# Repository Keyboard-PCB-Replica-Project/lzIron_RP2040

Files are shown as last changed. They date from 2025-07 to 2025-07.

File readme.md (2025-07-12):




LZ Iron 레플리카 PCB입니다. 

RGB LED 외의 LED(인디케이터)는 따로 부착해두지 않았습니다.

KT-0805W LED를 구입해서 LED 자리에 납땜해주시면 됩니다. 타오바오나 알리에서 같이 주문해주시면 되며,

납땜 난이도는 스위치보다도 못한 수준입니다.

물론 돈이 더 들어도 괜찮다면, LED까지 부착이 된 채로 배송 오는 옵션을 구현해두겠습니다.

이 기판은 MX 버전이며, ISO 엔터 및 Alps를 지원하지 않습니다!

추후에 추가될 수도 있습니다.

솔더링 버전이며, 아직 제작 후 제대로된 검증이 이뤄지지 않은 상태입니다!

검수는 꼼꼼이 했습니다.

이 기판은 LED와 USB가 전부 기판 전면부에 있기 때문에, 그 외의 SMD 부품들도 전부 전면메 배치했습니다.

간섭은 획인되지 않으나, 폼을 끼우고 빌드할 시 쇼트가 발생할 수 있습니다. 조심해주세요!

그리고 제가 실물 기판이 없어서, 사진을 보고 따 두었습니다.
스위치나 하우징과의 간섭이 없을지 이미지를 보고 잘 확인해보고 주문해주셨으면 해요.
저도 몇번씩 체크했지만 혹시 모르니까 재차 확인 부탁드려요!!

추가 필요 부품 : KT-0805W LED

작동 확인 여부 : 아직 확인되지 않음

----------------------------------------------------------

This is a replica PCB of the LZ Iron.

Indicator LEDs (other than RGB) are not included.

If you want them, you can buy KT-0805W LEDs and solder them yourself.

They’re easy to find on Taobao or AliExpress, and the soldering is even easier than doing switches.

If you're okay with spending a bit more, I might offer a version with the LEDs pre-installed later on.

This PCB supports MX switches only.

It doesn’t support ISO Enter or Alps switches (at least not yet — maybe in the future).

This is a solder-only version, and it hasn’t been fully tested yet.

But I did check everything carefully.

All components, including the LEDs and USB connector, are placed on the front side of the PCB.

Other SMD parts are also on the front.

There shouldn’t be any interference, but if you use case foam, be careful — there’s a chance of shorting.

Extra parts needed: KT-0805W LEDs

Tested and working: Not verified yet

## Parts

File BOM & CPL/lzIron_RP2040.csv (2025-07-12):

Reference | Value | Footprint | LCSC Part Number
C1,C2,C3,C4,C5,C6,C7,C8,C10,C11,C17,LC1,LC2,LC3,LC4,LC5,LC6,LC7,LC8 | 100n | C_0402 | C1525
C9,C12,C13,C14 | 1u | C_0402 | C52923
C15,C16 | 15p | C_0402 | C1548
D1,D2,D3,D4,D5,D6,D7,D8,D9,D10,D11,D12,D13,D14,D15,D16,D17,D18,D19,D20,D21,D22,D23,D24,D25,D26,D27,D28,D29,D30,D31,D32,D33,D34,D35,D36,D37,D38,D39,D40,D41,D42,D43,D44,D45,D46,D47,D48,D49,D50,D51,D52,D53,D54,D55,D56,D57,D58,D59,D60,D61,D62,D63,D64,D65,D66,D67,D68,D69,D70,D71,D72,D73,D74,D75,D76,D77,D78,D79,D80,D81,D82,D83,D84,D85,D86,D87,D88,D89 | D_Small | SOD-123 | C81598
F1 | Fuse_Small | F_0805 | C20978
J1 | USB_C_Receptacle_USB2.0_16P | USB_C_Receptacle_16P | C165948
R1,R2 | 27.4R | C_0603 | C25190
R3 | 10k | C_0402 | C25744
R4,R6 | 1k | C_0402 | C11702
R5,R8,R11 | 300R | C_0402 | C25102
R9,R10 | 5.1k | C_0402 | C25905
U1 | XC6206P332MR | SOT-23 | C5446
U2 | W25Q128JVS | SOIC-8_5.23x5.23mm | C97521
U3 | RP2040 | RP2040-QFN-56 | C2040
U4 | SRV05-4 | SOT-23-6 | C7420376
ULED1,ULED2,ULED3,ULED4,ULED5,ULED6,ULED7,ULED8 | SK6812MINI-HS | LED_SK6812MINI-HS | C2922787
Y1 | ABM8-272-T3 | XO32-4Pin_3.2x2.5 | C20625731

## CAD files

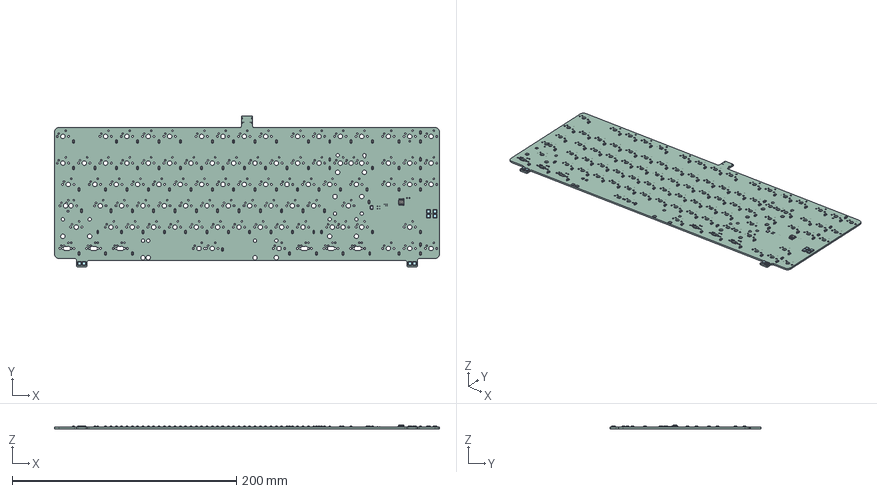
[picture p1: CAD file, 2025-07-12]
lzIron.step
343.7 x 135.1 x 3.50 mm
root x 89
SOIC8_P1-27_L5-0_W4-0
Product x 8
lzIron 1.67.1
lzIron 1.67.2
_autosave-lzIron_RP2040_PCB

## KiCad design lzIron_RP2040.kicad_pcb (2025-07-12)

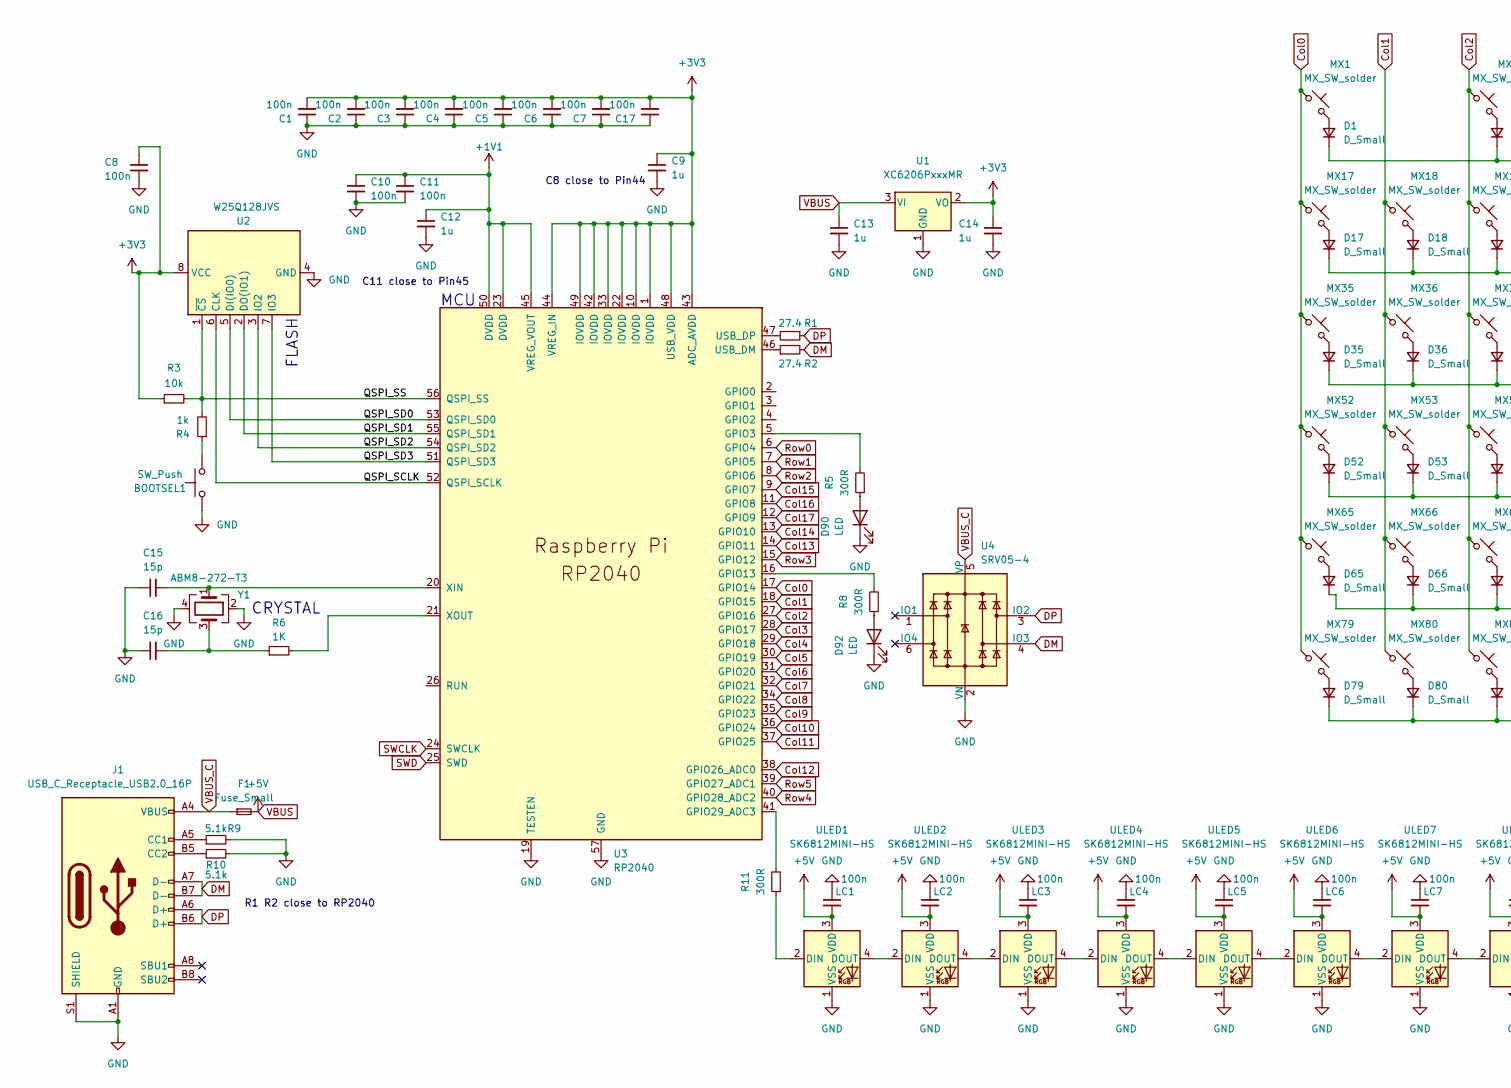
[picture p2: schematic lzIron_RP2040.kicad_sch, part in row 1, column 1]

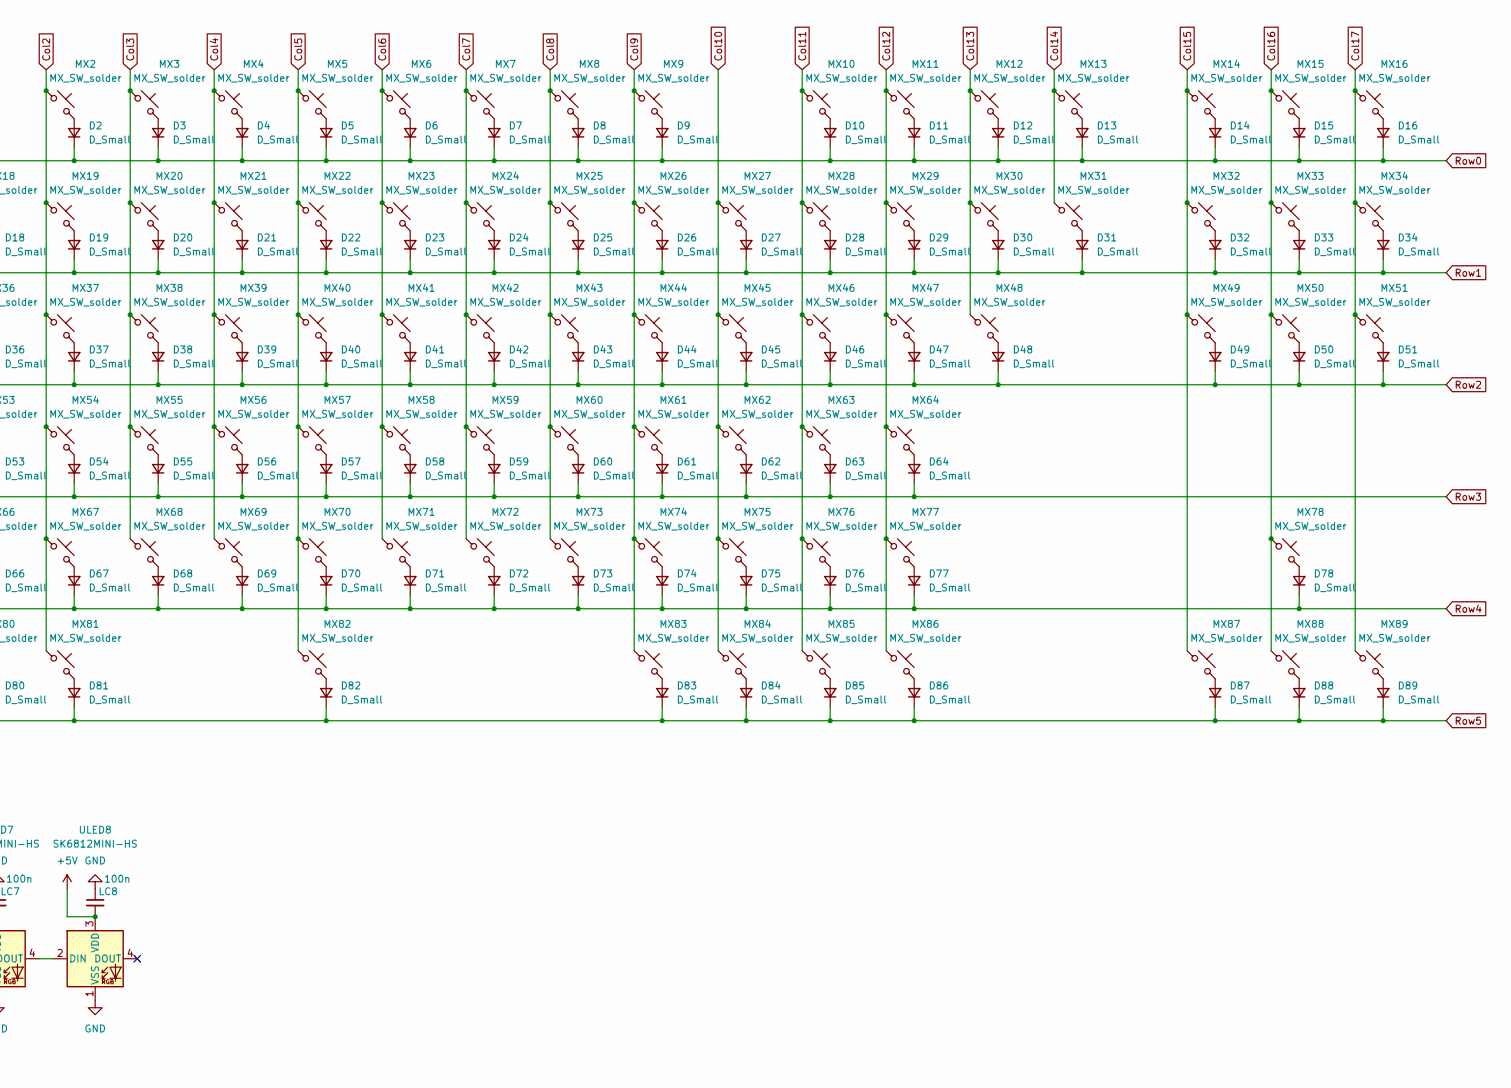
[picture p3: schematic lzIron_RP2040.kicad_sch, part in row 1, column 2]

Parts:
BOOTSEL1: SW_Push; two hole
C1, C2, C3, C4, C5, C6, C7, C8, C10, C11, C17: 100n; C_0402_1005Metric
C9, C12, C13, C14: 1u; C_0402_1005Metric
C15, C16: 15p; C_0402_1005Metric
D1, D2, D3, D4, D5, D6, D7, D8, D9, D10, D11, D12, D13, D14, D15, D16, D17, D18, D19, D20, D21, D22, D23, D24, D25, D26, D27, D28, D29, D30, D31, D32, D33, D34, D35, D36, D37, D38, D39, D40, D41, D42, D43, D44, D45, D46, D47, D48, D49, D50, D51, D52, D53, D54, D55, D56, D57, D58, D59, D60, D61, D62, D63, D64, D65, D66, D67, D68, D69, D70, D71, D72, D73, D74, D75, D76, D77, D78, D79, D80, D81, D82, D83, D84, D85, D86, D87, D88, D89: D_Small; Diode_SOD-123_noref2
D90, D92: LED; KT-0805W
F1: Fuse_Small; Fuse_0805_2012Metric_Pad1.15x1.40mm_HandSolder
J1: USB_C_Receptacle_USB2.0_16P; USB_C_Receptacle_GCT_USB4105-xx-A_16P_TopMnt_Horizontal
LC1, LC2, LC3, LC4, LC5, LC6, LC7, LC8: 100n; C_0402_1005Metric_noref
MX1, MX2, MX3, MX4, MX5, MX6, MX7, MX8, MX9, MX10, MX11, MX12, MX13, MX14, MX15, MX16, MX17, MX18, MX19, MX20, MX21, MX22, MX23, MX24, MX25, MX26, MX27, MX28, MX29, MX30, MX31, MX32, MX33, MX34, MX35, MX36, MX37, MX38, MX39, MX40, MX41, MX42, MX43, MX44, MX45, MX46, MX47, MX48, MX49, MX50, MX51, MX52, MX53, MX54, MX55, MX56, MX57, MX58, MX59, MX60, MX61, MX62, MX63, MX64, MX65, MX66, MX67, MX68, MX69, MX70, MX71, MX72, MX73, MX74, MX75, MX76, MX77, MX78, MX79, MX80, MX81, MX82, MX83, MX84, MX85, MX86, MX87, MX88, MX89: MX_SW_solder; MX_PCB_1.00u_NoSilkscreen3
R1, R2: 27.4; C_0603_1608Metric
R3: 10k; C_0402_1005Metric
R4: 1k; C_0402_1005Metric
R5, R8, R11: 300R; C_0402_1005Metric
R6: 1K; C_0402_1005Metric
R9, R10: 5.1k; C_0402_1005Metric
U1: XC6206PxxxMR; SOT-23
U2: W25Q128JVS; SOIC-8_5.23x5.23mm_P1.27mm
U3: RP2040; RP2040-QFN-56
U4: SRV05-4; SOT-23-6
ULED1, ULED2, ULED3, ULED4, ULED5, ULED6, ULED7, ULED8: SK6812MINI-HS; LED_SK6812MINI_PLCC4_3.5x3.5mm_P1.75mm_2
Y1: ABM8-272-T3; Oscillator_SMD_EuroQuartz_XO32-4Pin_3.2x2.5mm

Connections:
+1V1: C10.1, C11.1, C12.1, U3.23 (DVDD), U3.45 (VREG_VOUT), U3.50 (DVDD)
+3V3: C1.2, C2.2, C3.2, C4.2, C5.2, C6.2, C7.2, C8.1, C9.1, C14.1, C17.2, R3.1, U1.2 (VO), U2.8 (VCC), U3.1 (IOVDD), U3.10 (IOVDD), U3.22 (IOVDD), U3.33 (IOVDD), U3.42 (IOVDD), U3.43 (ADC_AVDD), U3.44 (VREG_IN), U3.48 (USB_VDD), U3.49 (IOVDD)
/QSPI_SCLK: U2.6 (CLK), U3.52 (QSPI_SCLK)
/QSPI_SD0: U2.5 (DI(IO0)), U3.53 (QSPI_SD0)
/QSPI_SD1: U2.2 (DO(IO1)), U3.55 (QSPI_SD1)
/QSPI_SD2: U2.3 (IO2), U3.54 (QSPI_SD2)
/QSPI_SD3: U2.7 (IO3), U3.51 (QSPI_SD3)
/QSPI_SS: R3.2, R4.2, U2.1 (~CS), U3.56 (QSPI_SS)
Col0: MX1.1, MX17.1, MX35.1, MX52.1, MX65.1, MX79.1, U3.17 (GPIO14)
Col1: MX18.1, MX36.1, MX53.1, MX66.1, MX80.1, U3.18 (GPIO15)
Col2: MX2.1, MX19.1, MX37.1, MX54.1, MX67.1, MX81.1, U3.27 (GPIO16)
Col3: MX3.1, MX20.1, MX38.1, MX55.1, MX68.1, U3.28 (GPIO17)
Col4: MX4.1, MX21.1, MX39.1, MX56.1, MX69.1, U3.29 (GPIO18)
Col5: MX5.1, MX22.1, MX40.1, MX57.1, MX70.1, MX82.1, U3.30 (GPIO19)
Col6: MX6.1, MX23.1, MX41.1, MX58.1, MX71.1, U3.31 (GPIO20)
Col7: MX7.1, MX24.1, MX42.1, MX59.1, MX72.1, U3.32 (GPIO21)
Col8: MX8.1, MX25.1, MX43.1, MX60.1, MX73.1, U3.34 (GPIO22)
Col9: MX9.1, MX26.1, MX44.1, MX61.1, MX74.1, MX83.1, U3.35 (GPIO23)
Col10: MX27.1, MX45.1, MX62.1, MX75.1, MX84.1, U3.36 (GPIO24)
Col11: MX10.1, MX28.1, MX46.1, MX63.1, MX76.1, MX85.1, U3.37 (GPIO25)
Col12: MX11.1, MX29.1, MX47.1, MX64.1, MX77.1, MX86.1, U3.38 (GPIO26_ADC0)
Col13: MX12.1, MX30.1, MX48.1, U3.14 (GPIO11)
Col14: MX13.1, MX31.1, U3.13 (GPIO10)
Col15: MX14.1, MX32.1, MX49.1, MX87.1, U3.9 (GPIO7)
Col16: MX15.1, MX33.1, MX50.1, MX78.1, MX88.1, U3.11 (GPIO8)
Col17: MX16.1, MX34.1, MX51.1, MX89.1, U3.12 (GPIO9)
DM: J1.A7 (D-), J1.B7 (D-), R2.2, U4.4 (IO3)
DP: J1.A6 (D+), J1.B6 (D+), R1.1, U4.3 (IO2)
GND: BOOTSEL1.1, C1.1, C2.1, C3.1, C4.1, C5.1, C6.1, C7.1, C8.2, C9.2, C10.2, C11.2, C12.2, C13.2, C14.2, C15.1, C16.1, C17.1, D90.1 (K), D92.1 (K), J1.A1 (GND), J1.A12 (GND), J1.B1 (GND), J1.B12 (GND), J1.S1 (SHIELD), LC1.1, LC2.1, LC3.1, LC4.1, LC5.1, LC6.1, LC7.1, LC8.1, R9.2, R10.2, U1.1 (GND), U2.4 (GND), U3.19 (TESTEN), U3.57 (GND), U4.2 (VN), ULED1.1 (VSS), ULED2.1 (VSS), ULED3.1 (VSS), ULED4.1 (VSS), ULED5.1 (VSS), ULED6.1 (VSS), ULED7.1 (VSS), ULED8.1 (VSS), Y1.2, Y1.4
unnamed: BOOTSEL1.2, R4.1
unnamed: C16.2, R6.1, Y1.3
unnamed: D1.2 (A), MX1.2
unnamed: D2.2 (A), MX2.2
unnamed: D3.2 (A), MX3.2
unnamed: D4.2 (A), MX4.2
unnamed: D5.2 (A), MX5.2
unnamed: D6.2 (A), MX6.2
unnamed: D7.2 (A), MX7.2
unnamed: D8.2 (A), MX8.2
unnamed: D9.2 (A), MX9.2
unnamed: D10.2 (A), MX10.2
unnamed: D11.2 (A), MX11.2
unnamed: D12.2 (A), MX12.2
unnamed: D13.2 (A), MX13.2
unnamed: D14.2 (A), MX14.2
unnamed: D15.2 (A), MX15.2
unnamed: D16.2 (A), MX16.2
unnamed: D17.2 (A), MX17.2
unnamed: D18.2 (A), MX18.2
unnamed: D19.2 (A), MX19.2
unnamed: D20.2 (A), MX20.2
unnamed: D21.2 (A), MX21.2
unnamed: D22.2 (A), MX22.2
unnamed: D23.2 (A), MX23.2
unnamed: D24.2 (A), MX24.2
unnamed: D25.2 (A), MX25.2
unnamed: D26.2 (A), MX26.2
unnamed: D27.2 (A), MX27.2
unnamed: D28.2 (A), MX28.2
unnamed: D29.2 (A), MX29.2
unnamed: D30.2 (A), MX30.2
unnamed: D31.2 (A), MX31.2
unnamed: D32.2 (A), MX32.2
unnamed: D33.2 (A), MX33.2
unnamed: D34.2 (A), MX34.2
unnamed: D35.2 (A), MX35.2
unnamed: D36.2 (A), MX36.2
unnamed: D37.2 (A), MX37.2
unnamed: D38.2 (A), MX38.2
unnamed: D39.2 (A), MX39.2
unnamed: D40.2 (A), MX40.2
unnamed: D41.2 (A), MX41.2
unnamed: D42.2 (A), MX42.2
unnamed: D43.2 (A), MX43.2
unnamed: D44.2 (A), MX44.2
unnamed: D45.2 (A), MX45.2
unnamed: D46.2 (A), MX46.2
unnamed: D47.2 (A), MX47.2
unnamed: D48.2 (A), MX48.2
unnamed: D49.2 (A), MX49.2
unnamed: D50.2 (A), MX50.2
unnamed: D51.2 (A), MX51.2
unnamed: D52.2 (A), MX52.2
unnamed: D53.2 (A), MX53.2
unnamed: D54.2 (A), MX54.2
unnamed: D55.2 (A), MX55.2
unnamed: D56.2 (A), MX56.2
unnamed: D57.2 (A), MX57.2
unnamed: D58.2 (A), MX58.2
unnamed: D59.2 (A), MX59.2
unnamed: D60.2 (A), MX60.2
unnamed: D61.2 (A), MX61.2
unnamed: D62.2 (A), MX62.2
unnamed: D63.2 (A), MX63.2
unnamed: D64.2 (A), MX64.2
unnamed: D65.2 (A), MX65.2
unnamed: D66.2 (A), MX66.2
unnamed: D67.2 (A), MX67.2
unnamed: D68.2 (A), MX68.2
unnamed: D69.2 (A), MX69.2
unnamed: D70.2 (A), MX70.2
unnamed: D71.2 (A), MX71.2
unnamed: D72.2 (A), MX72.2
unnamed: D73.2 (A), MX73.2
unnamed: D74.2 (A), MX74.2
unnamed: D75.2 (A), MX75.2
unnamed: D76.2 (A), MX76.2
unnamed: D77.2 (A), MX77.2
unnamed: D78.2 (A), MX78.2
unnamed: D79.2 (A), MX79.2
unnamed: D80.2 (A), MX80.2
unnamed: D81.2 (A), MX81.2
unnamed: D82.2 (A), MX82.2
unnamed: D83.2 (A), MX83.2
unnamed: D84.2 (A), MX84.2
unnamed: D85.2 (A), MX85.2
unnamed: D86.2 (A), MX86.2
unnamed: D87.2 (A), MX87.2
unnamed: D88.2 (A), MX88.2
unnamed: D89.2 (A), MX89.2
unnamed: D90.2 (A), R5.1
unnamed: D92.2 (A), R8.1
unnamed: J1.A5 (CC1), R9.1
unnamed: J1.B5 (CC2), R10.1
unnamed: R5.2, U3.5 (GPIO3)
unnamed: R8.2, U3.16 (GPIO13)
unnamed: R11.2, U3.41 (GPIO29_ADC3)
unnamed: R2.1, U3.46 (USB_DM)
unnamed: R1.2, U3.47 (USB_DP)
unnamed: C15.2, U3.20 (XIN), Y1.1
unnamed: R6.2, U3.21 (XOUT)
unnamed: R11.1, ULED1.2 (DIN)
unnamed: ULED1.4 (DOUT), ULED2.2 (DIN)
unnamed: ULED2.4 (DOUT), ULED3.2 (DIN)
unnamed: ULED3.4 (DOUT), ULED4.2 (DIN)
unnamed: ULED4.4 (DOUT), ULED5.2 (DIN)
unnamed: ULED5.4 (DOUT), ULED6.2 (DIN)
unnamed: ULED6.4 (DOUT), ULED7.2 (DIN)
unnamed: ULED7.4 (DOUT), ULED8.2 (DIN)
Row0: D1.1 (K), D2.1 (K), D3.1 (K), D4.1 (K), D5.1 (K), D6.1 (K), D7.1 (K), D8.1 (K), D9.1 (K), D10.1 (K), D11.1 (K), D12.1 (K), D13.1 (K), D14.1 (K), D15.1 (K), D16.1 (K), U3.6 (GPIO4)
Row1: D17.1 (K), D18.1 (K), D19.1 (K), D20.1 (K), D21.1 (K), D22.1 (K), D23.1 (K), D24.1 (K), D25.1 (K), D26.1 (K), D27.1 (K), D28.1 (K), D29.1 (K), D30.1 (K), D31.1 (K), D32.1 (K), D33.1 (K), D34.1 (K), U3.7 (GPIO5)
Row2: D35.1 (K), D36.1 (K), D37.1 (K), D38.1 (K), D39.1 (K), D40.1 (K), D41.1 (K), D42.1 (K), D43.1 (K), D44.1 (K), D45.1 (K), D46.1 (K), D47.1 (K), D48.1 (K), D49.1 (K), D50.1 (K), D51.1 (K), U3.8 (GPIO6)
Row3: D52.1 (K), D53.1 (K), D54.1 (K), D55.1 (K), D56.1 (K), D57.1 (K), D58.1 (K), D59.1 (K), D60.1 (K), D61.1 (K), D62.1 (K), D63.1 (K), D64.1 (K), U3.15 (GPIO12)
Row4: D65.1 (K), D66.1 (K), D67.1 (K), D68.1 (K), D69.1 (K), D70.1 (K), D71.1 (K), D72.1 (K), D73.1 (K), D74.1 (K), D75.1 (K), D76.1 (K), D77.1 (K), D78.1 (K), U3.40 (GPIO28_ADC2)
Row5: D79.1 (K), D80.1 (K), D81.1 (K), D82.1 (K), D83.1 (K), D84.1 (K), D85.1 (K), D86.1 (K), D87.1 (K), D88.1 (K), D89.1 (K), U3.39 (GPIO27_ADC1)
SWCLK: U3.24 (SWCLK)
SWD: U3.25 (SWD)
VBUS: C13.1, F1.2, LC1.2, LC2.2, LC3.2, LC4.2, LC5.2, LC6.2, LC7.2, LC8.2, U1.3 (VI), ULED1.3 (VDD), ULED2.3 (VDD), ULED3.3 (VDD), ULED4.3 (VDD), ULED5.3 (VDD), ULED6.3 (VDD), ULED7.3 (VDD), ULED8.3 (VDD)
VBUS_C: F1.1, J1.A4 (VBUS), J1.A9 (VBUS), J1.B4 (VBUS), J1.B9 (VBUS), U4.5 (VP)

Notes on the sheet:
MCU
FLASH
R1 R2 close to RP2040
C8 close to Pin44
CRYSTAL
C11 close to Pin45

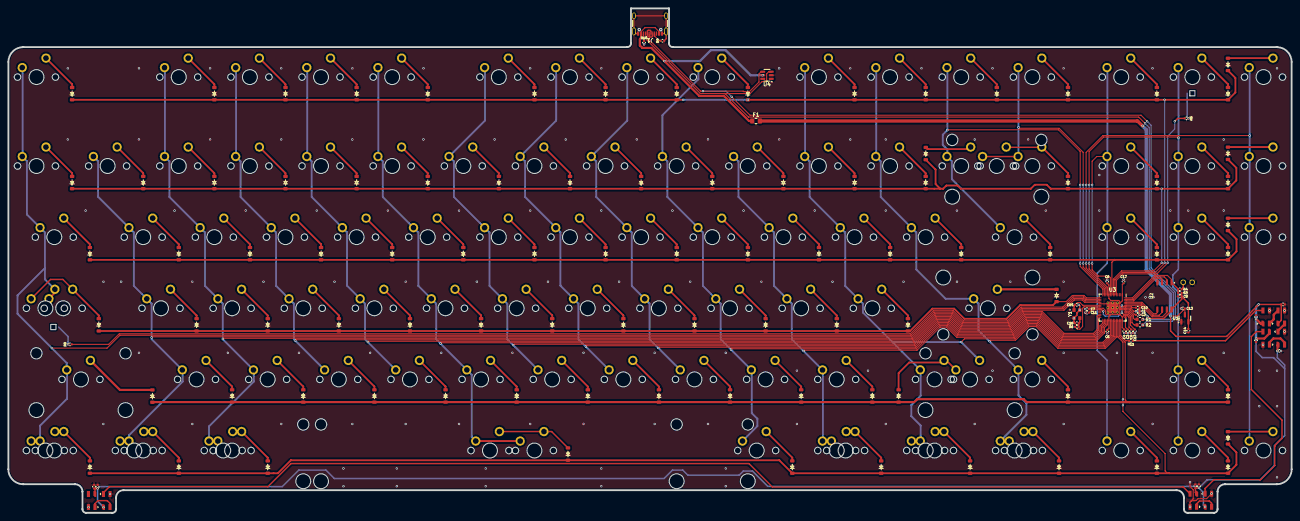
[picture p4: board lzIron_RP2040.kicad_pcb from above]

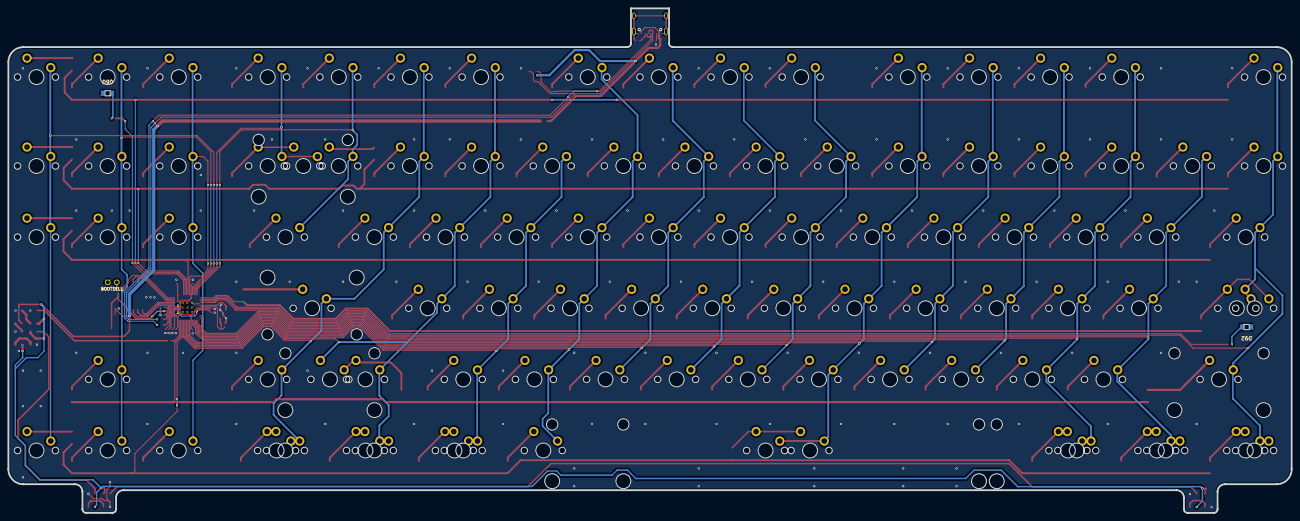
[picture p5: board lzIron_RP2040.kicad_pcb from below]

Board: 2 copper layers, 343.7 x 135.1 mm, 231 parts (2 on the bottom side), 147 nets.
